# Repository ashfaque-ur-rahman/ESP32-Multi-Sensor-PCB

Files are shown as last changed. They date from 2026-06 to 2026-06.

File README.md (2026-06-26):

# ESP32-C3 Multi-Sensor PCB — 4-Layer Board
 
My most complex PCB design to date — an ESP32-C3 based multi-sensor IoT board featuring three sensors across a hierarchical, multi-sheet schematic. Designed over multiple days following the **Tech Explorations** tutorial series. This was my first experience with both 4-layer PCB stackup design and microphone amplifier circuit design.
 
---
 
## Preview
 
### Schematic — Root Page
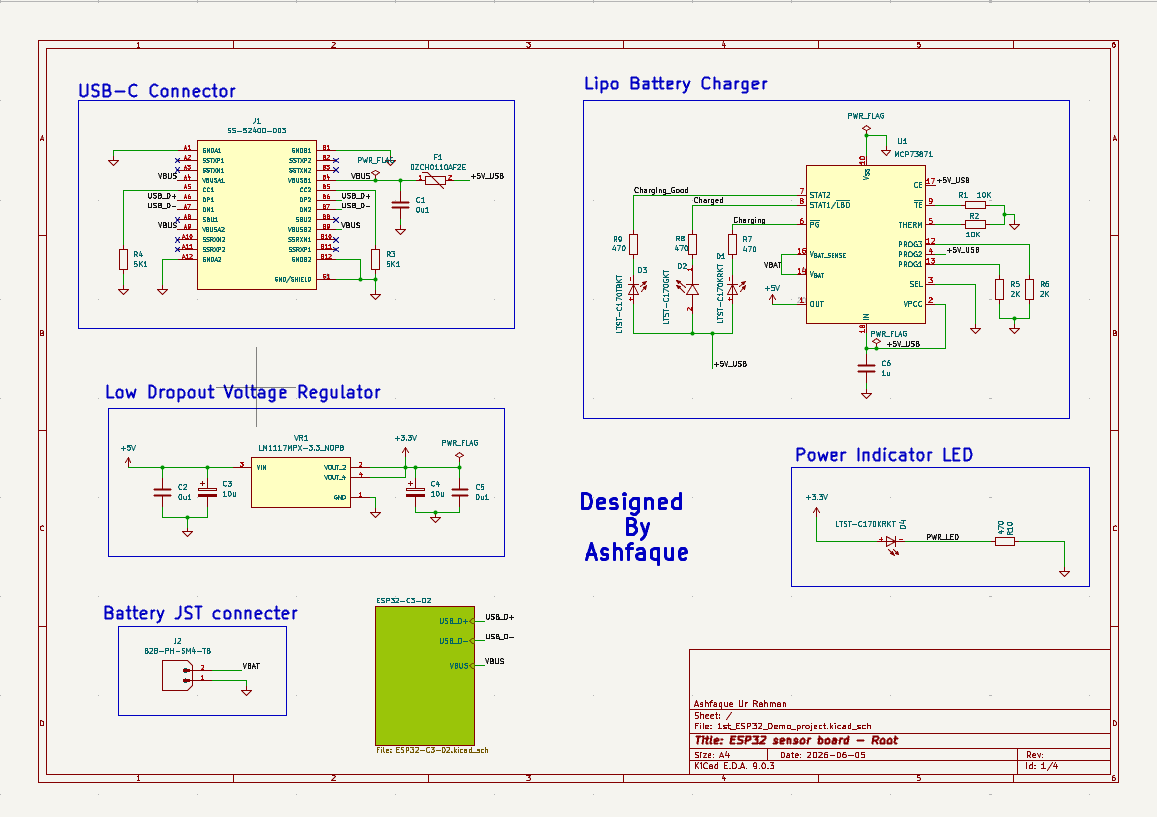
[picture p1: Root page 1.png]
Root Schematic

 
### Schematic — Sensors Sheet
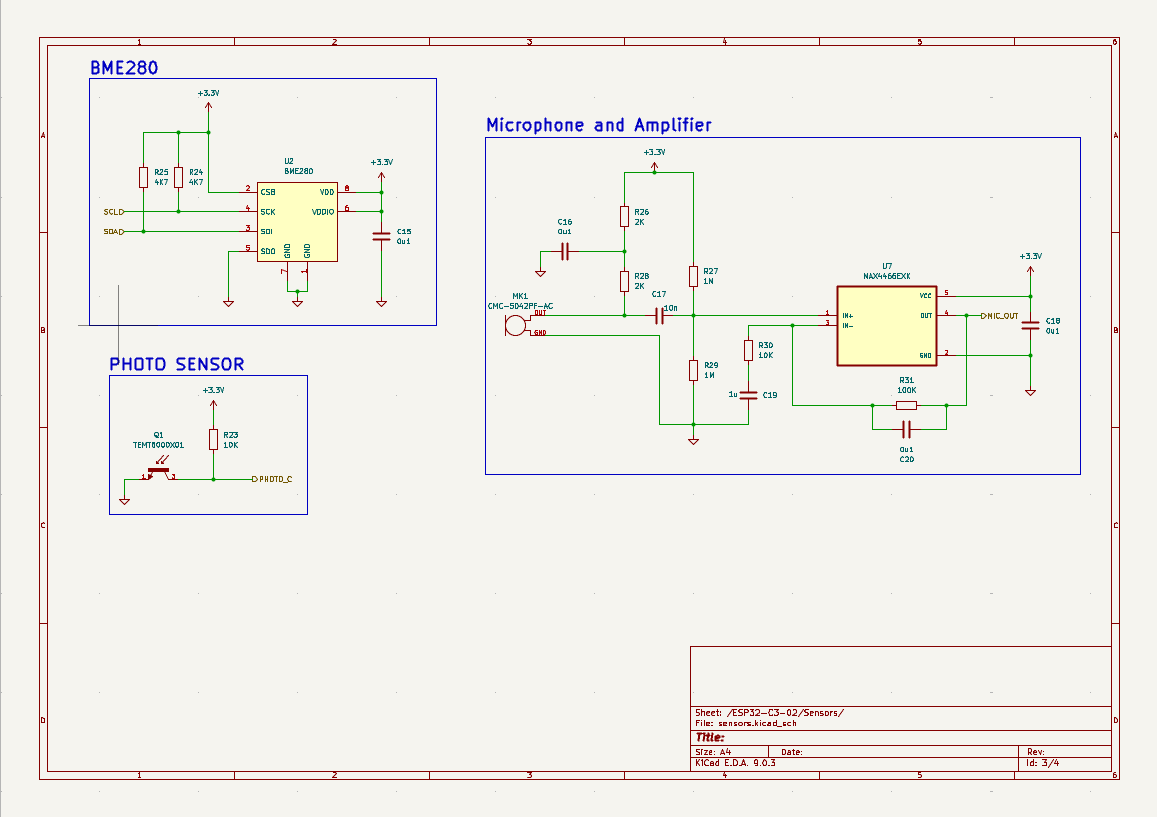
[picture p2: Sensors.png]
Sensors Schematic

 
### Schematic — Page 2
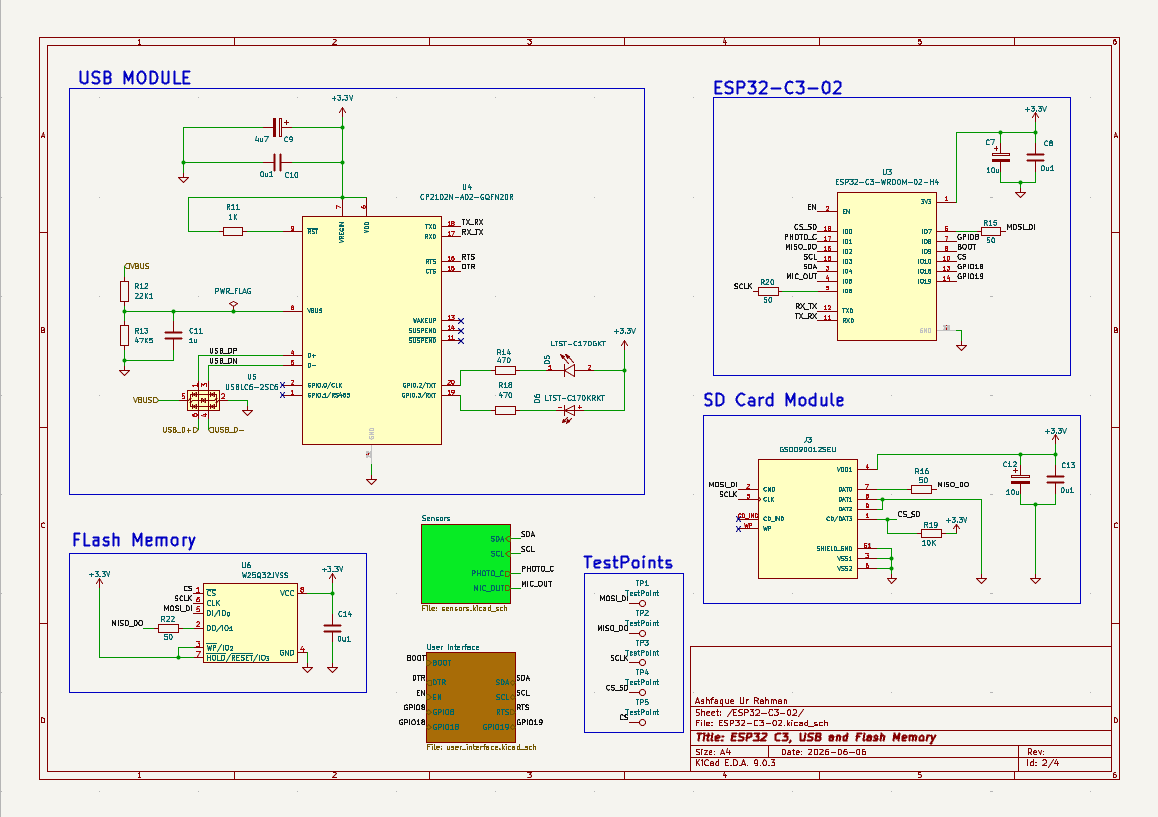
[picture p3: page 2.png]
Schematic Page 2

 
### Schematic — User Interface Sheet
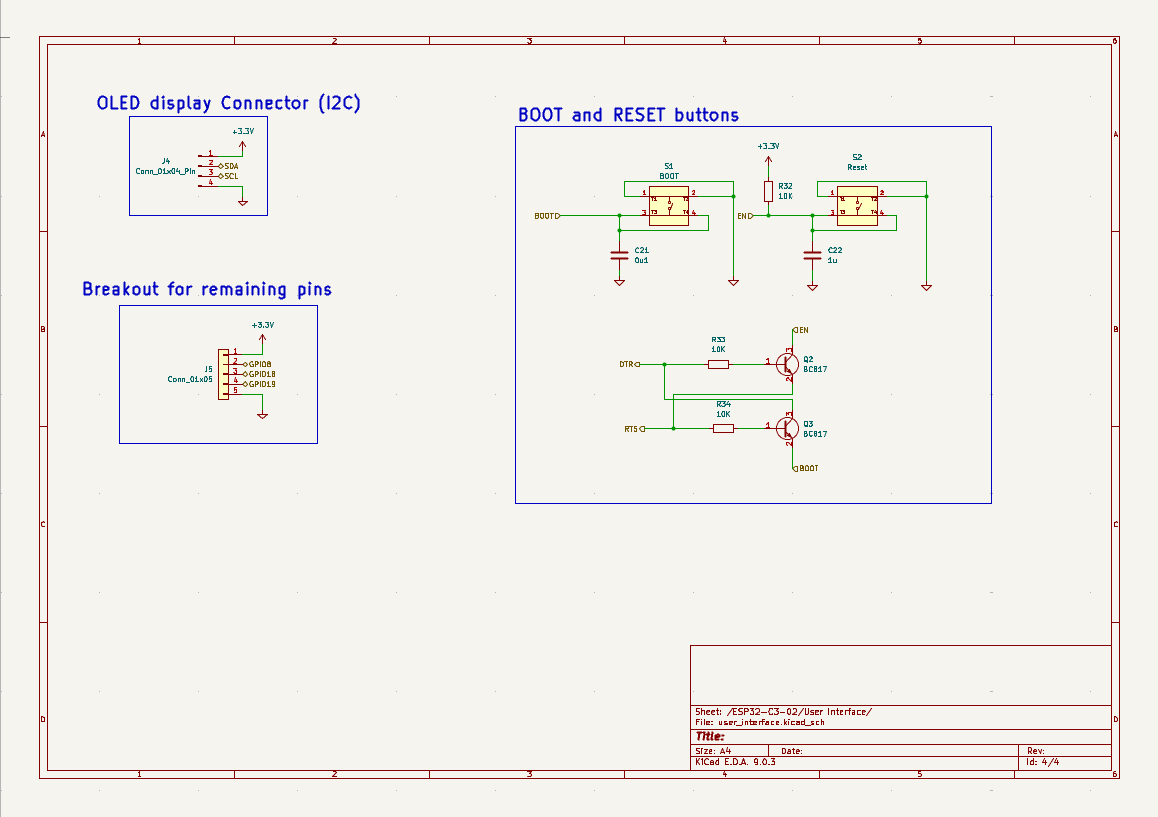
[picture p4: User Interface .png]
User Interface Schematic

 
### PCB Layout
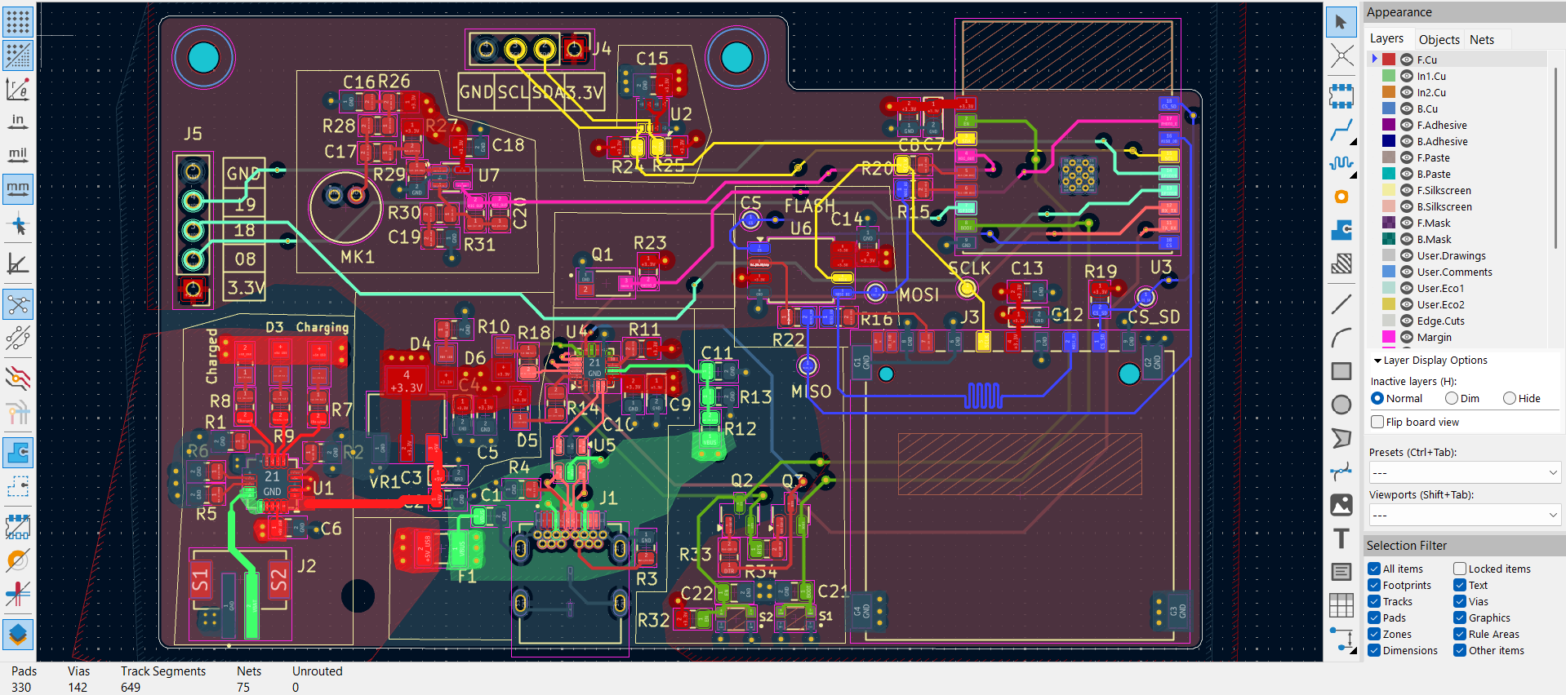
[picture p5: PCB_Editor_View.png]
PCB Layout

 
### 3D View
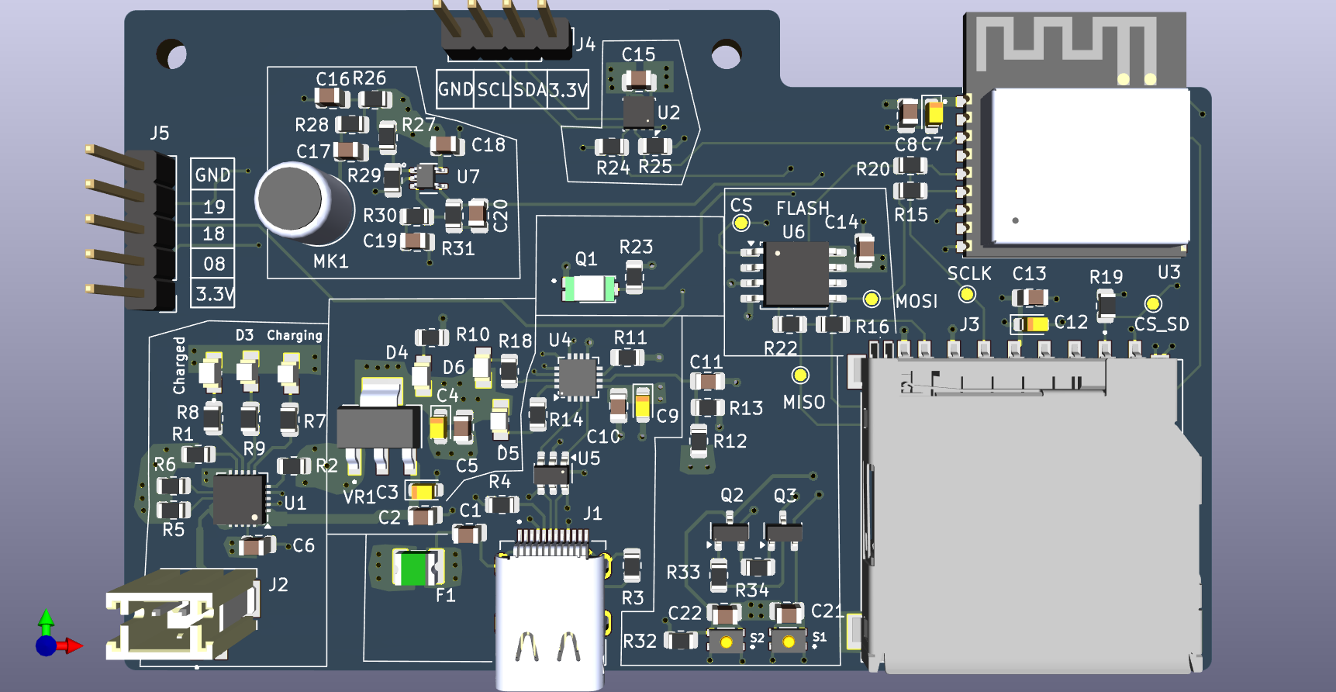
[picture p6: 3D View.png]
3D View

 
---
 
## Project overview
 
| Property | Details |
|---|---|
| **MCU** | ESP32-C3 |
| **Board layers** | 4-layer stackup |
| **Schematic structure** | Hierarchical — 3 separate sheets |
| **Sensors** | BME280, Electret Microphone + MAX4466EXK |
| **EDA Tool** | KiCad 9.0 |
| **Design reference** | Tech Explorations tutorial series |
| **Status** | Design complete |
 
---
 
## Board stackup
 
| Layer | Function |
|---|---|
| Layer 1 (Top) | Signal + components |
| Layer 2 | Ground plane (GND) |
| Layer 3 | Power plane (VCC) |
| Layer 4 (Bottom) | Signal |
 
A dedicated ground plane on Layer 2 ensures low-impedance returns for all sensors and clean power distribution — critical for analog microphone signal integrity.
 
---
 
## Sensors & key components
 
| Component | Part | Function | Interface |
|---|---|---|---|
| Environmental Sensor | BME280 (Bosch) | Temperature, humidity & pressure — 3-in-1 | I²C / SPI |
| Microphone | CMC-5042PF-AC (Same Sky) | 6mm omnidirectional electret condenser mic | Analog |
| Mic Amplifier | MAX4466EXK (Analog Devices) | Low-noise microphone amplifier, SC-70 package | Analog |
| MCU | ESP32-C3-02 | Wi-Fi + Bluetooth 5.0 LE microcontroller | — |
 
---
 
## Schematic structure
 
This design uses a **hierarchical multi-sheet schematic** — a professional approach for managing complex designs:
 
| Sheet | Contents |
|---|---|
| `Root page 1` | Top-level hierarchy, power distribution, ESP32-C3 core |
| `sensors.kicad_sch` | BME280 environmental sensor + microphone + MAX4466 amplifier circuit |
| `user_interface.kicad_sch` | User-facing connections, GPIO breakouts, connectors |
 
---
 
## Files included
 
### KiCad project files
| File | Description |
|---|---|
| `1st_ESP32_Demo_project.kicad_pro` | KiCad project file |
| `1st_ESP32_Demo_project.kicad_sch` | Root schematic |
| `ESP32-C3-02.kicad_sch` | ESP32-C3 sub-schematic sheet |
| `sensors.kicad_sch` | Sensors sub-schematic sheet |
| `user_interface.kicad_sch` | User interface sub-schematic sheet |
| `1st_ESP32_Demo_project.kicad_pcb` | PCB layout |
| `Footprints/` | Custom footprint library |
 
---
 
## What I learned
 
- 4-layer PCB stackup design with dedicated ground and power planes
- Hierarchical multi-sheet schematic design in KiCad 9.0
- BME280 I²C sensor integration with proper decoupling
- Electret condenser microphone biasing and signal conditioning
- MAX4466EXK low-noise amplifier circuit design
- Analog signal routing considerations on a mixed-signal PCB
- ESP32-C3 peripheral assignment and RF antenna clearance
---
 
## Tools used
 


 
---
 
## Reference
 
This design follows the **Tech Explorations ESP32 PCB Design tutorial series**.
 
> Tech Explorations: [https://www.youtube.com/@TechExplorations](https://www.youtube.com/@TechExplorations)
 
---
 
*Mymensingh Engineering College — EEE Department*

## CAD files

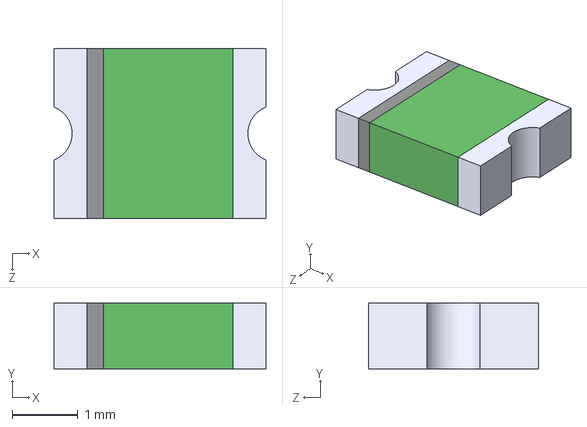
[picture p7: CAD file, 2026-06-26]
Footprints/0ZCH0110AF2E/0ZCH0110AF2E.step
3.21 x 1.00 x 2.58 mm

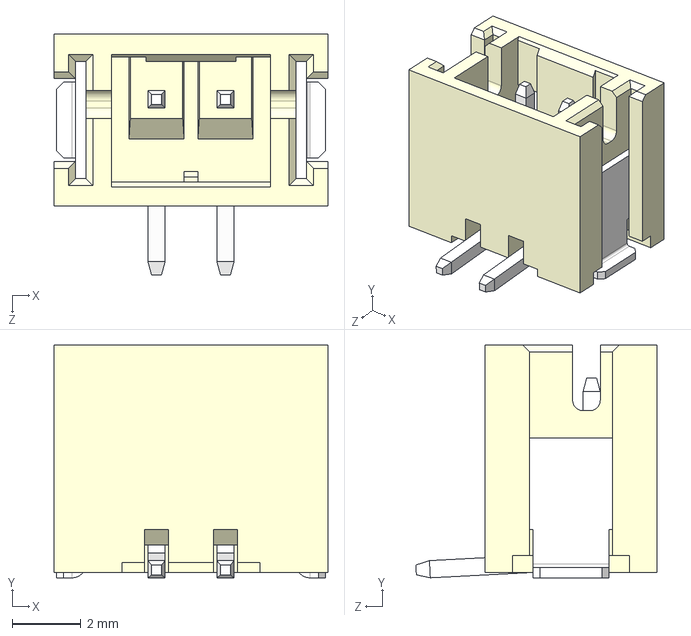
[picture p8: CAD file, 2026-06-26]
Footprints/B2B-PH-SM4-TB/B2B-PH-SM4-TB.step
7.95 x 6.75 x 7.00 mm

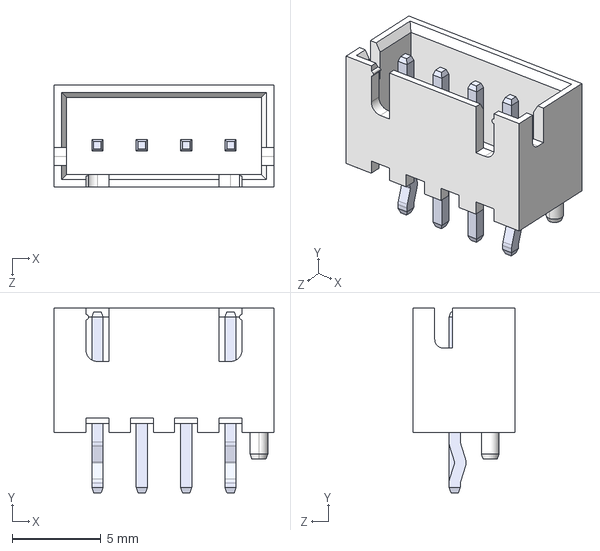
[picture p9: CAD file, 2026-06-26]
Footprints/B4B-XH-AM__LF__SN_/B4B-XH-AM__LF__SN_.step
12.4 x 10.4 x 5.75 mm

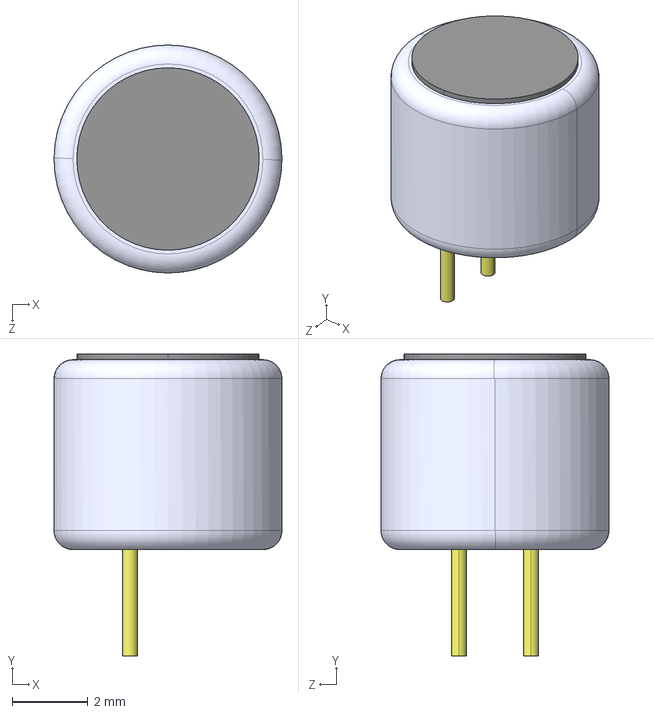
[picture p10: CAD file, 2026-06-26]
Footprints/CMC-5042PF-AC/CMC-5042PF-AC.step
6.00 x 7.95 x 6.00 mm

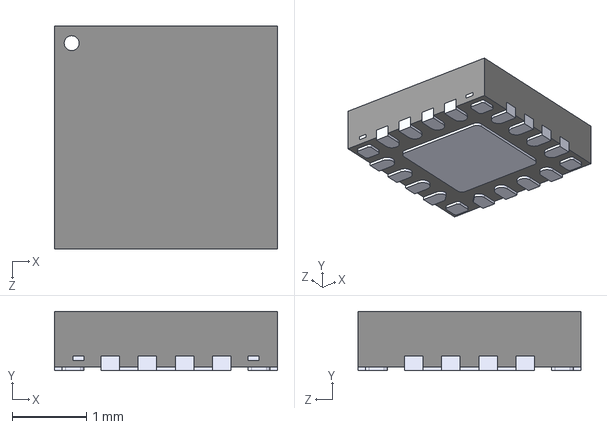
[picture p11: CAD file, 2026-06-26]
Footprints/CP2102N-A02-GQFN20R/CP2102N-A02-GQFN20R--3DModel-STEP-510211.STEP
3.00 x 0.8 x 3.00 mm

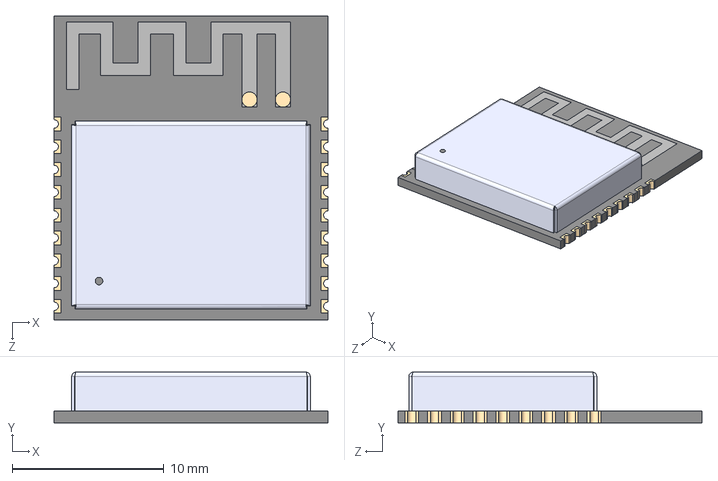
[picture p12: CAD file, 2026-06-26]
Footprints/ESP32-C3-WROOM-02-H4/ESP32-C3-WROOM-02-H4.step
18.0 x 3.35 x 20.0 mm

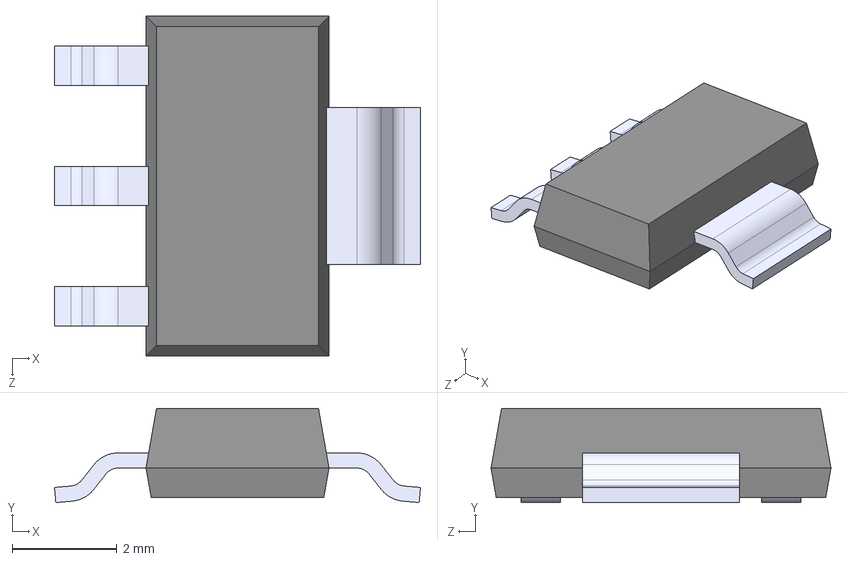
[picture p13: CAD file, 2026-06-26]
Footprints/LM1117MPX-3.3_NOPB/LM1117MPX-3.3_NOPB.step
7.00 x 1.80 x 6.50 mm

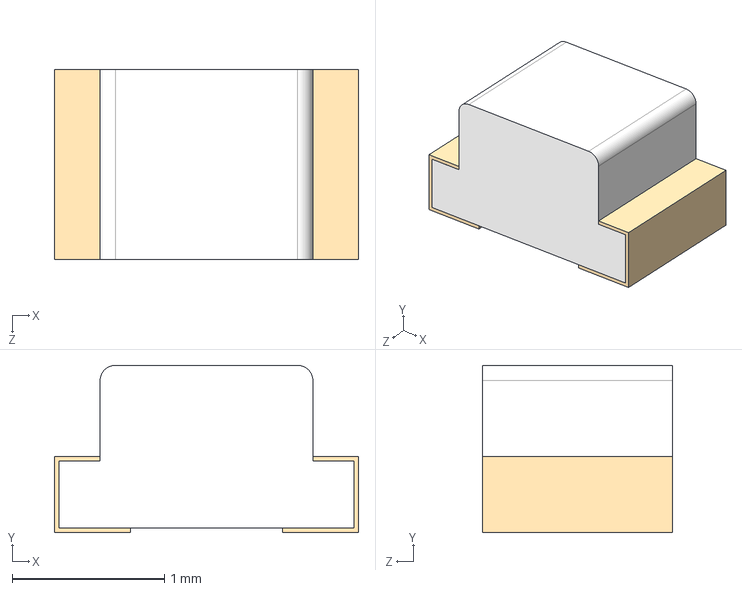
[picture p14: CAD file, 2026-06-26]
Footprints/LTST-C170GKT/LTST-C170GKT.step
2.00 x 1.10 x 1.25 mm

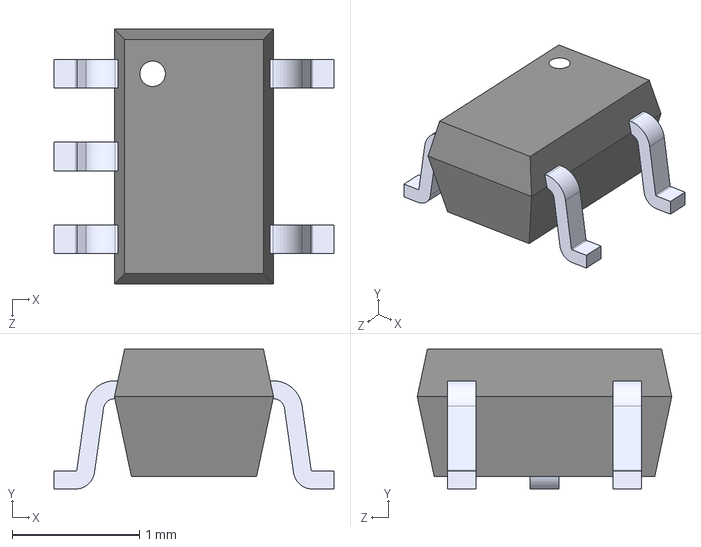
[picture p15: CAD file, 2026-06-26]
Footprints/MAX4466EXK/MAX4466EXK.step
2.20 x 1.10 x 2.00 mm

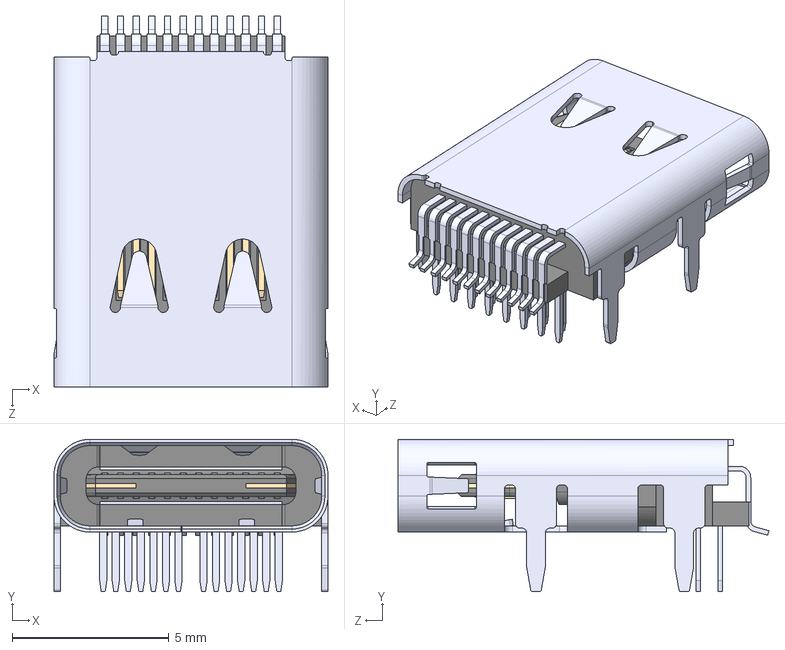
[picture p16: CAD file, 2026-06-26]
Footprints/SS-52400-003/SS-52400-003--3DModel-STEP-56544.STEP
8.74 x 4.86 x 11.8 mm

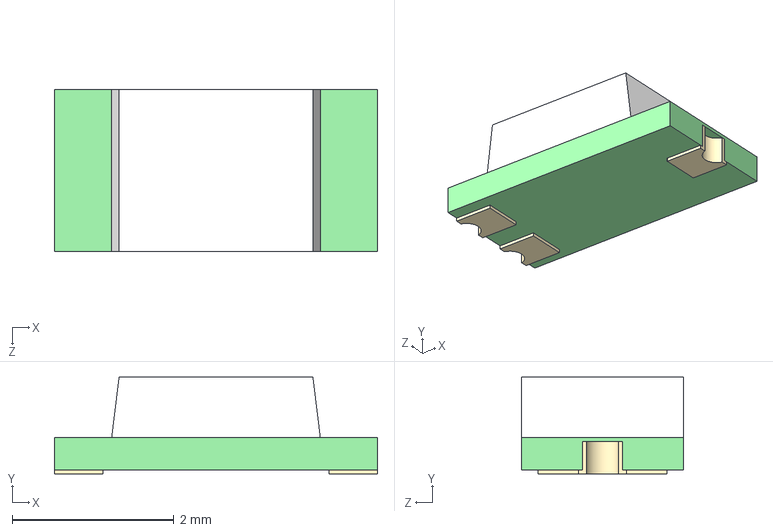
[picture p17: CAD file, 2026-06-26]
Footprints/TEMT6000X01/TEMT6000X01.step
4.00 x 1.20 x 2.00 mm

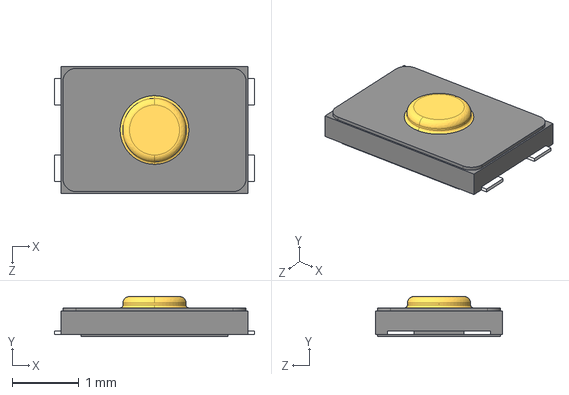
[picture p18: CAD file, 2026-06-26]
Footprints/USLPT2819DT2TR/USLPT2819DT2TR.step
3.00 x 0.6 x 1.90 mm

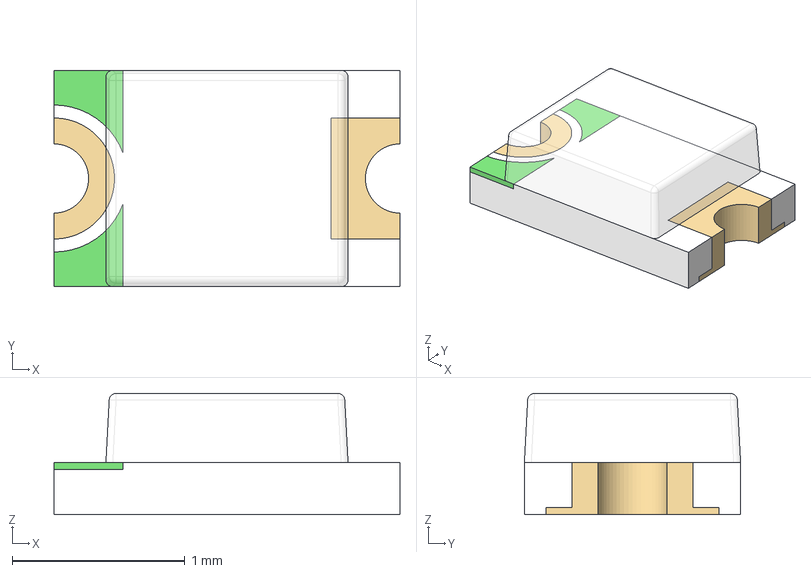
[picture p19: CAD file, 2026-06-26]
Footprints/WL-SMCW_0805/WL-SMCW_0805.step
2.00 x 1.25 x 0.7 mm
housing
marking x 2
cover
base_2
base

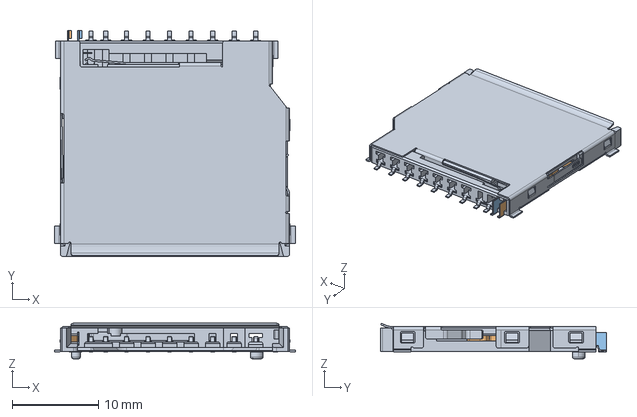
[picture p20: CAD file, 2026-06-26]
Footprints/GSD090012SEU/GSD090012SEU.step
28.0 x 26.2 x 4.13 mm

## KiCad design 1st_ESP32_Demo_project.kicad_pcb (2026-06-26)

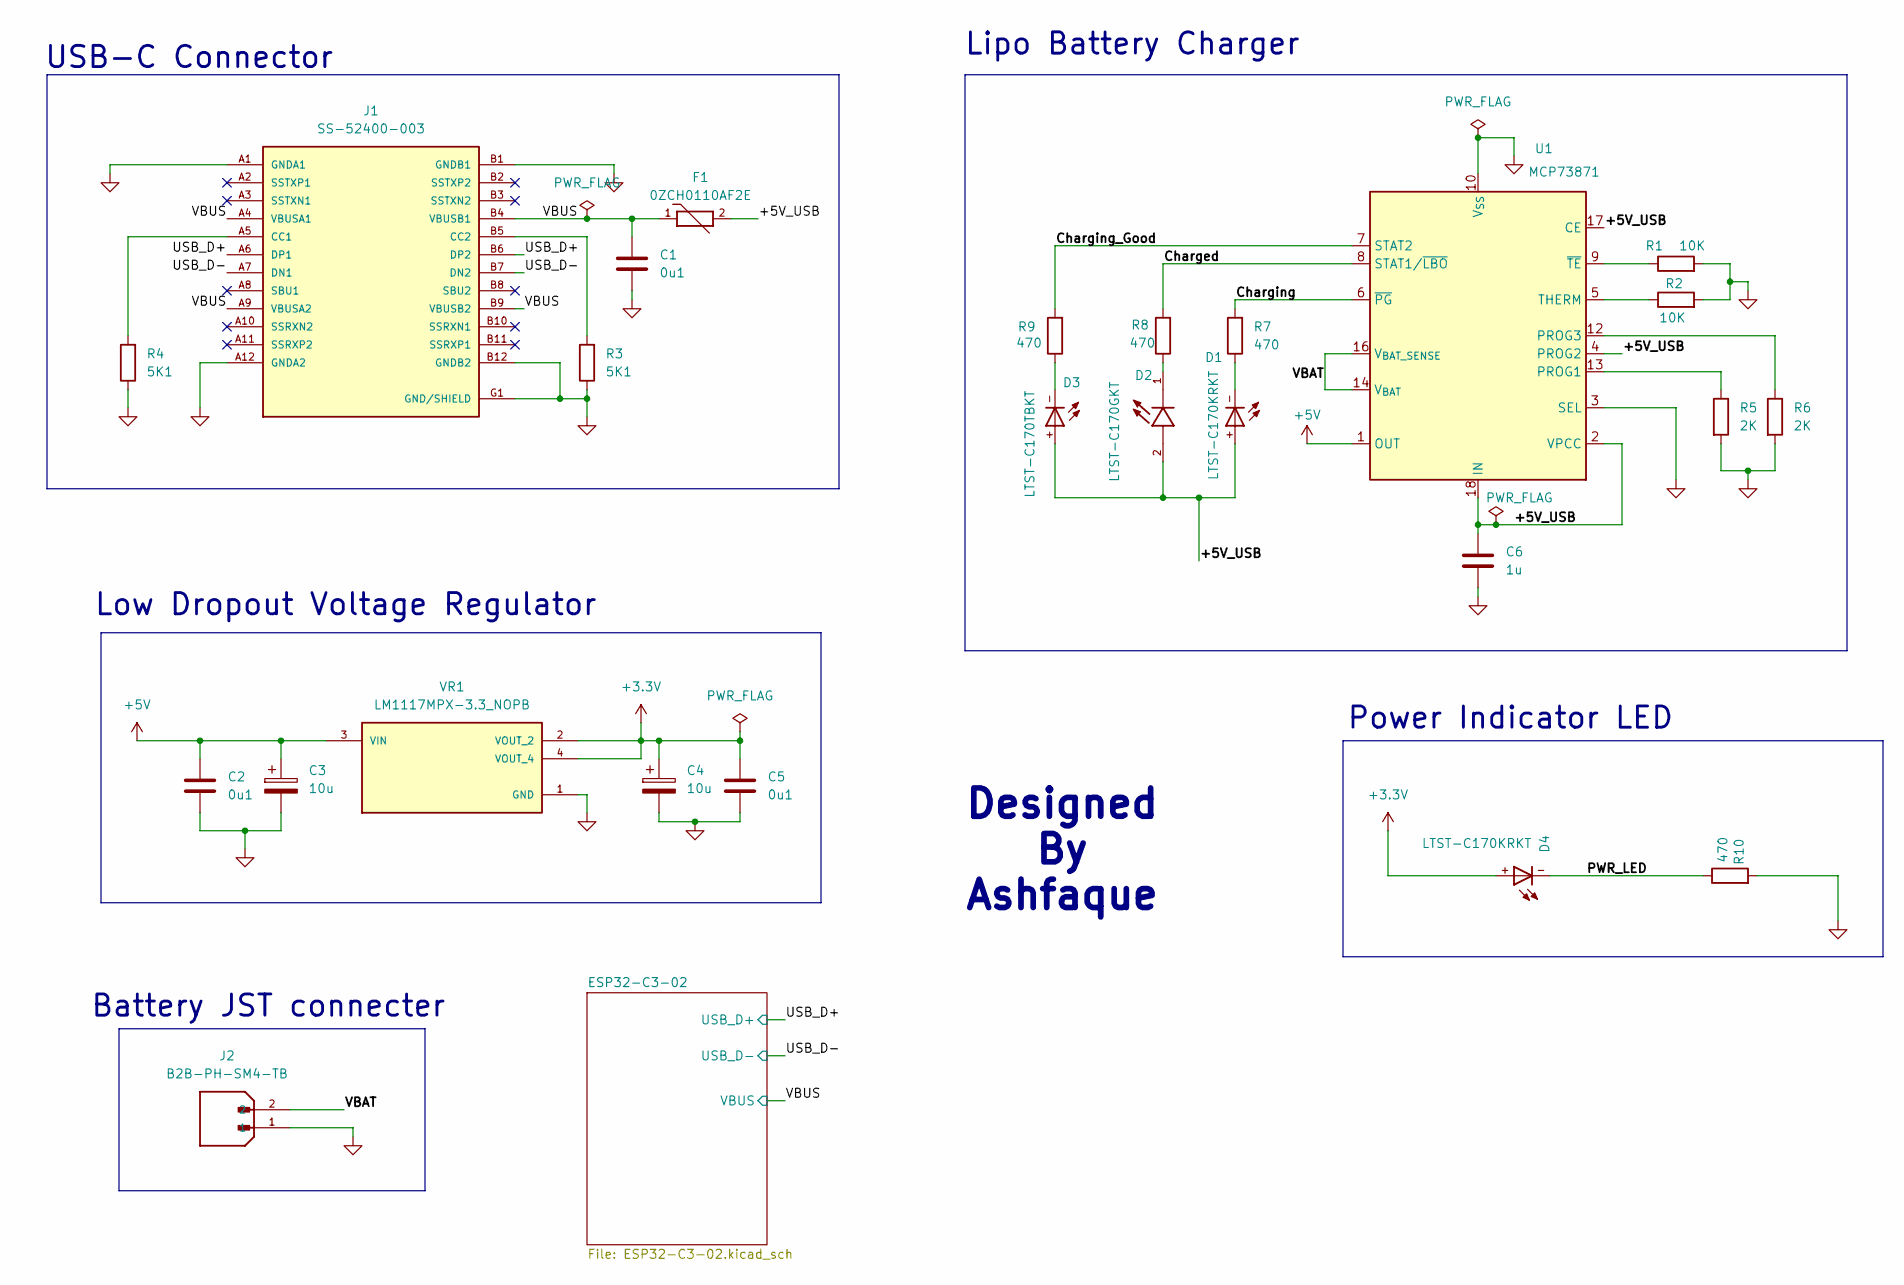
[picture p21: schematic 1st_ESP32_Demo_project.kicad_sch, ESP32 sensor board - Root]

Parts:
C1, C2, C5: 0u1; C_0805_2012Metric
C3, C4: 10u; CP_EIA-2012-12_Kemet-R
C6: 1u; C_0805_2012Metric
D1, D4: LTST-C170KRKT; DIOC200X125X110
D2: LTST-C170GKT; LED_LTST-C170GKT; PARTREV I
D3: LTST-C170TBKT; DIOC200X125X110
F1: 0ZCH0110AF2E; FUSC3225X100N; PARTREV Apr2023
J1: SS-52400-003; BELFUSE_SS-52400-003; PARTREV A0
J2: B2B-PH-SM4-TB; JST_B2B-PH-SM4-TB; PARTREV N/A
R1, R2: 10K; R_0805_2012Metric
R3, R4: 5K1; R_0805_2012Metric
R5, R6: 2K; R_0805_2012Metric
R7, R8, R9, R10: 470; R_0805_2012Metric
U1: MCP73871; QFN-20-1EP_4x4mm_P0.5mm_EP2.5x2.5mm
VR1: LM1117MPX-3.3_NOPB; VREG_LM1117MPX-3.3_NOPB; PARTREV O

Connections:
+3.3V: C4.1, C5.1, D4.+, VR1.2 (VOUT_2), VR1.4 (VOUT_4); also elsewhere on the board
+5V: C2.1, C3.1, U1.1 (OUT), U1.20 (OUT), VR1.3 (VIN)
/+5V_USB: C6.1, D1.+, D2.2, D3.+, F1.2, U1.2 (VPCC), U1.4 (PROG2), U1.17 (CE), U1.18 (IN), U1.19 (IN); also elsewhere on the board
/Charged: R8.2, U1.8 (STAT1/~LBO)
/Charging: R7.2, U1.6 (~PG)
/Charging_Good: R9.2, U1.7 (STAT2)
/PWR_LED: D4.-, R10.1
/USB_D+: J1.A6 (DP1), J1.B6 (DP2); also elsewhere on the board
/USB_D-: J1.A7 (DN1), J1.B7 (DN2); also elsewhere on the board
/VBAT: J2.2, U1.14 (V_{BAT}), U1.15 (V_{BAT}), U1.16 (V_{BAT_SENSE})
/VBUS: C1.1, F1.1, J1.A4 (VBUSA1), J1.A9 (VBUSA2), J1.B4 (VBUSB1), J1.B9 (VBUSB2); also elsewhere on the board
GND: C1.2, C2.2, C3.2, C4.2, C5.2, C6.2, J1.A1 (GNDA1), J1.A12 (GNDA2), J1.B1 (GNDB1), J1.B12 (GNDB2), J1.G1 (GND/SHIELD), J1.G2 (GND/SHIELD), J1.G3 (GND/SHIELD), J1.G4 (GND/SHIELD), J1.S1 (GND/SHIELD), J1.S2 (GND/SHIELD), J1.S3 (GND/SHIELD), J1.S4 (GND/SHIELD), J2.1, R1.2, R2.2, R3.1, R4.1, R5.2, R6.2, R10.2, U1.3 (SEL), U1.10 (V_{SS}), U1.11 (V_{SS}), U1.21 (V_{SS}), VR1.1 (GND); also elsewhere on the board
unnamed 35: D1.-, R7.1; also elsewhere on the board
unnamed 36: D2.1, R8.1; also elsewhere on the board
unnamed: D3.-, R9.1
unnamed: J1.A5 (CC1), R4.2
unnamed: J1.B5 (CC2), R3.2
unnamed: R5.1, U1.13 (PROG1)
unnamed: R6.1, U1.12 (PROG3)
unnamed: R2.1, U1.5 (THERM)
unnamed: R1.1, U1.9 (~TE)

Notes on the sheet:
Lipo Battery Charger
USB-C Connector
Battery JST connecter
Designed By Ashfaque
Power Indicator LED
Low Dropout Voltage Regulator

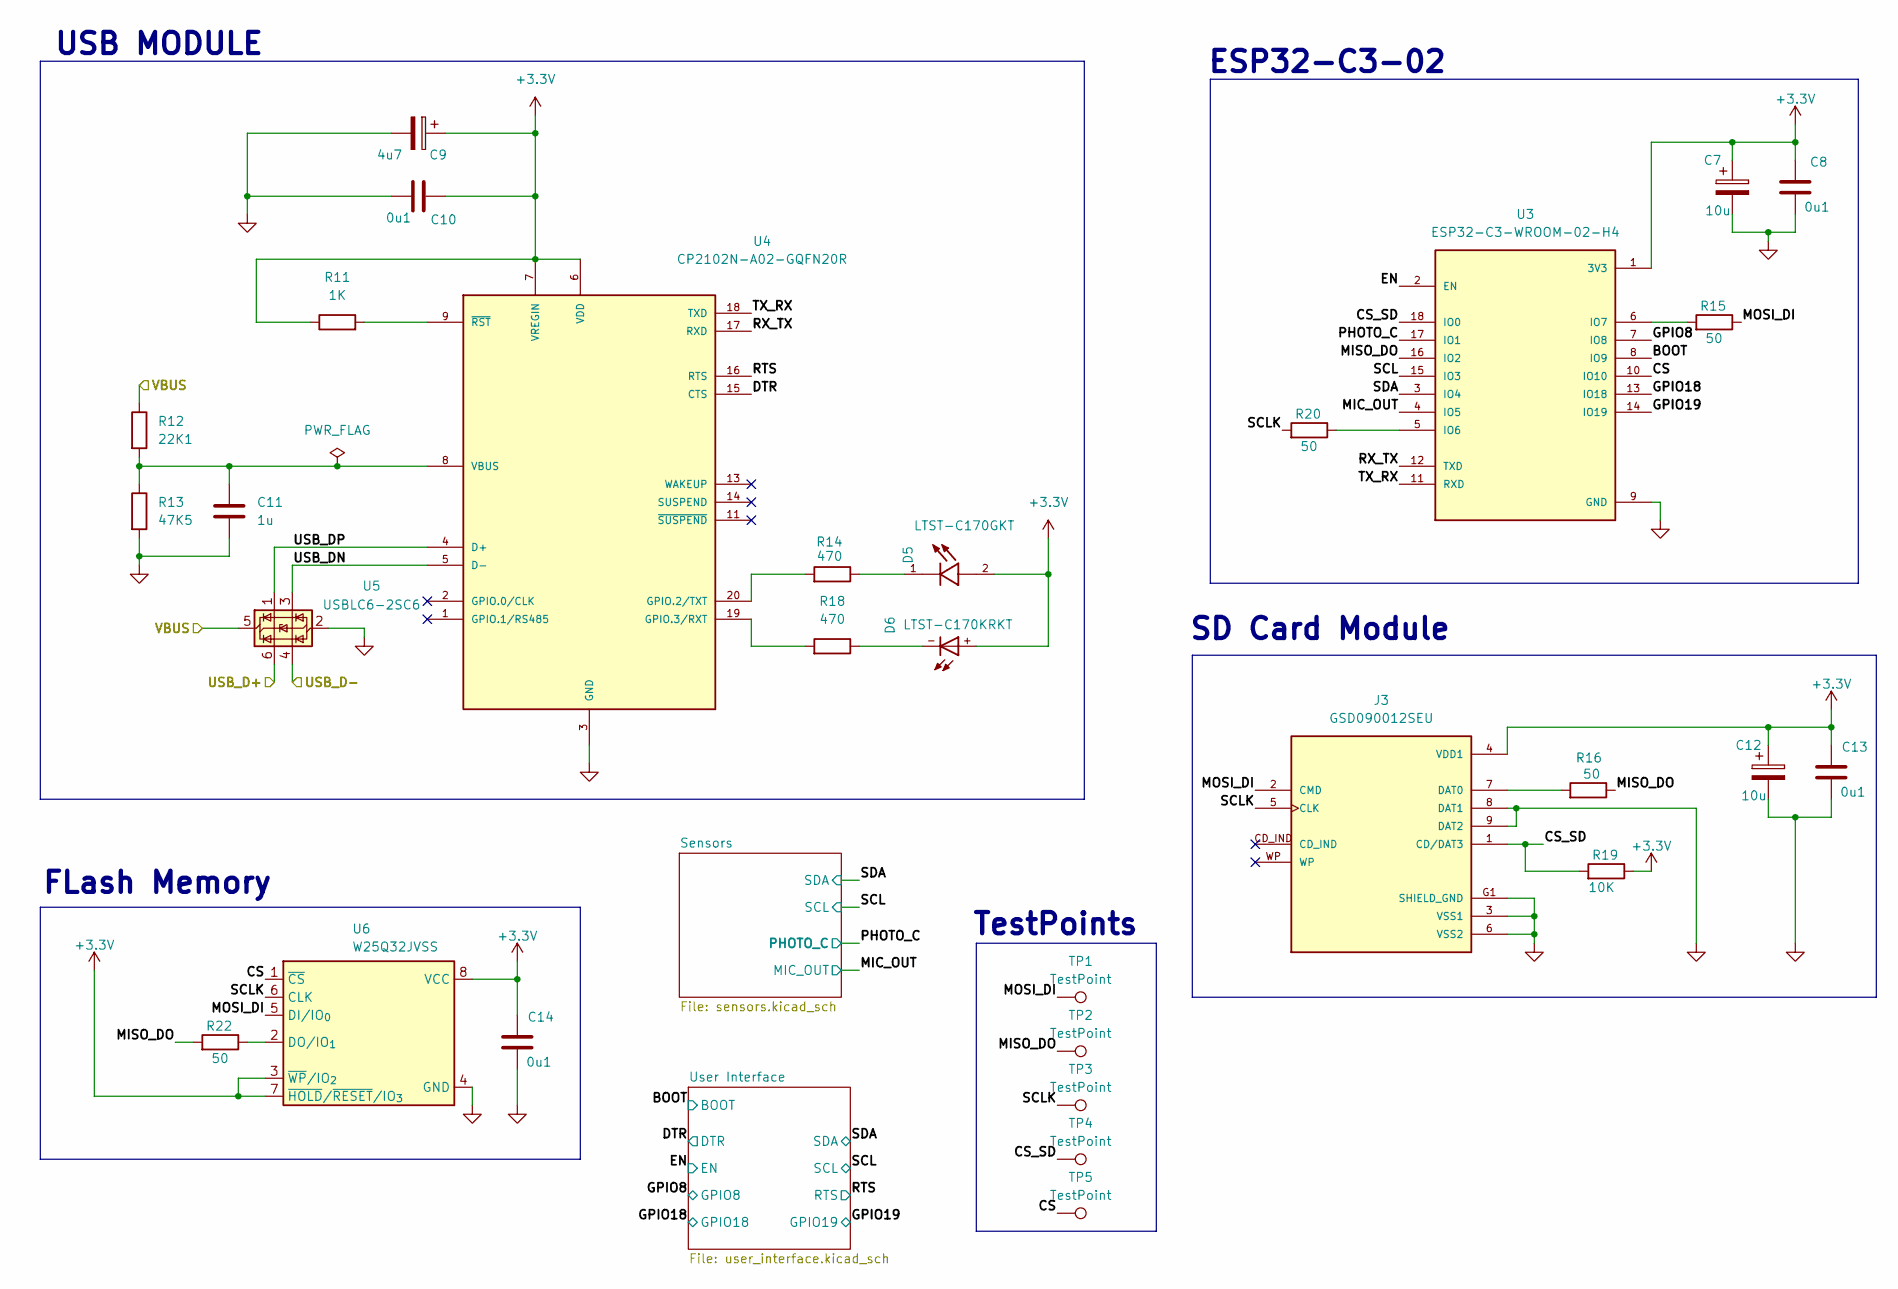
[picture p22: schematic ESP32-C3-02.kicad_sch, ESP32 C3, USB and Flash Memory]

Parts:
C7, C12: 10u; CP_EIA-2012-12_Kemet-R
C8, C10, C13, C14: 0u1; C_0805_2012Metric
C9: 4u7; CP_EIA-2012-12_Kemet-R
C11: 1u; C_0805_2012Metric
D5: LTST-C170GKT; LED_LTST-C170GKT; PARTREV I
D6: LTST-C170KRKT; DIOC200X125X110
J3: GSD090012SEU; AMPHENOL_GSD090012SEU; PARTREV E
R11: 1K; R_0805_2012Metric
R12: 22K1; R_0805_2012Metric
R13: 47K5; R_0805_2012Metric
R14, R18: 470; R_0805_2012Metric
R15, R16, R20, R22: 50; R_0805_2012Metric
R19: 10K; R_0805_2012Metric
TP1, TP2, TP3, TP4, TP5: TestPoint; TestPoint_Pad_D1.0mm
U3: ESP32-C3-WROOM-02-H4; MODULE_ESP32-C3-WROOM-02-H4
U4: CP2102N-A02-GQFN20R; SiliconLabs_QFN-20-1EP_3x3mm_P0.5mm_EP1.8x1.8mm; PARTREV 1.3
U5: USBLC6-2SC6; SOT-23-6
U6: W25Q32JVSS; SOIC-8_5.3x5.3mm_P1.27mm

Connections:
+3.3V: C7.1, C8.2, C9.1, C10.2, C12.1, C13.2, C14.2, D5.2, D6.+, J3.4 (VDD1), R11.1, R19.1, U3.1 (3V3), U4.6 (VDD), U4.7 (VREGIN), U6.3 (~WP/IO_{2}), U6.7 (~HOLD/~RESET/IO_{3}), U6.8 (VCC); also elsewhere on the board
/ESP32-C3-02/BOOT: U3.8 (IO9); also elsewhere on the board
/ESP32-C3-02/CS: TP5.1, U3.10 (IO10), U6.1 (~CS); also elsewhere on the board
/ESP32-C3-02/CS_SD: J3.1 (CD/DAT3), R19.2, TP4.1, U3.18 (IO0); also elsewhere on the board
/ESP32-C3-02/DTR: U4.15 (CTS); also elsewhere on the board
/ESP32-C3-02/EN: U3.2 (EN); also elsewhere on the board
/ESP32-C3-02/GPIO8: U3.7 (IO8); also elsewhere on the board
/ESP32-C3-02/GPIO18: U3.13 (IO18); also elsewhere on the board
/ESP32-C3-02/GPIO19: U3.14 (IO19); also elsewhere on the board
/ESP32-C3-02/MIC_OUT: U3.4 (IO5); also elsewhere on the board
/ESP32-C3-02/MISO_DO: R16.1, R22.2, TP2.1, U3.16 (IO2); also elsewhere on the board
/ESP32-C3-02/MOSI_DI: J3.2 (CMD), R15.1, TP1.1, U6.5 (DI/IO_{0}); also elsewhere on the board
/ESP32-C3-02/PHOTO_C: U3.17 (IO1); also elsewhere on the board
/ESP32-C3-02/RTS: U4.16 (RTS); also elsewhere on the board
/ESP32-C3-02/RX_TX: U3.12 (TXD), U4.17 (RXD)
/ESP32-C3-02/SCL: U3.15 (IO3); also elsewhere on the board
/ESP32-C3-02/SCLK: J3.5 (CLK), R20.2, TP3.1, U6.6 (CLK); also elsewhere on the board
/ESP32-C3-02/SDA: U3.3 (IO4); also elsewhere on the board
/ESP32-C3-02/TX_RX: U3.11 (RXD), U4.18 (TXD)
/ESP32-C3-02/USB_DN: U4.5 (D-), U5.3 (I/O2)
/ESP32-C3-02/USB_DP: U4.4 (D+), U5.1 (I/O1)
/USB_D+: U5.6 (I/O1); also elsewhere on the board
/USB_D-: U5.4 (I/O2); also elsewhere on the board
/VBUS: R12.1, U5.5 (VBUS); also elsewhere on the board
GND: C7.2, C8.1, C9.2, C10.1, C11.2, C12.2, C13.1, C14.1, J3.3 (VSS1), J3.6 (VSS2), J3.8 (DAT1), J3.9 (DAT2), J3.G1 (SHIELD_GND), J3.G2 (SHIELD_GND), J3.G3 (SHIELD_GND), J3.G4 (SHIELD_GND), R13.2, U3.9 (GND), U3.19 (GND), U3.20 (GND), U3.21 (GND), U3.22 (GND), U3.23 (GND), U3.24 (GND), U3.25 (GND), U3.26 (GND), U3.27 (GND), U3.28 (GND), U3.29 (GND), U3.30 (GND), U3.31 (GND), U3.32 (GND), U3.33 (GND), U3.34 (GND), U3.35 (GND), U3.36 (GND), U3.37 (GND), U3.38 (GND), U3.39 (GND), U4.3 (GND), U4.12 (GND), U4.21 (GND), U5.2 (GND), U6.4 (GND); also elsewhere on the board
unnamed: D5.1, R14.1
unnamed: D6.-, R18.1
unnamed: J3.7 (DAT0), R16.2
unnamed: R20.1, U3.5 (IO6)
unnamed: R15.2, U3.6 (IO7)
unnamed: R14.2, U4.20 (GPIO.2/TXT)
unnamed: R18.2, U4.19 (GPIO.3/RXT)
unnamed: C11.1, R12.2, R13.1, U4.8 (VBUS)
unnamed: R11.2, U4.9 (~RST)
unnamed: R22.1, U6.2 (DO/IO_{1})

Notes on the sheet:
USB MODULE
FLash Memory
ESP32-C3-02
TestPoints
SD Card Module

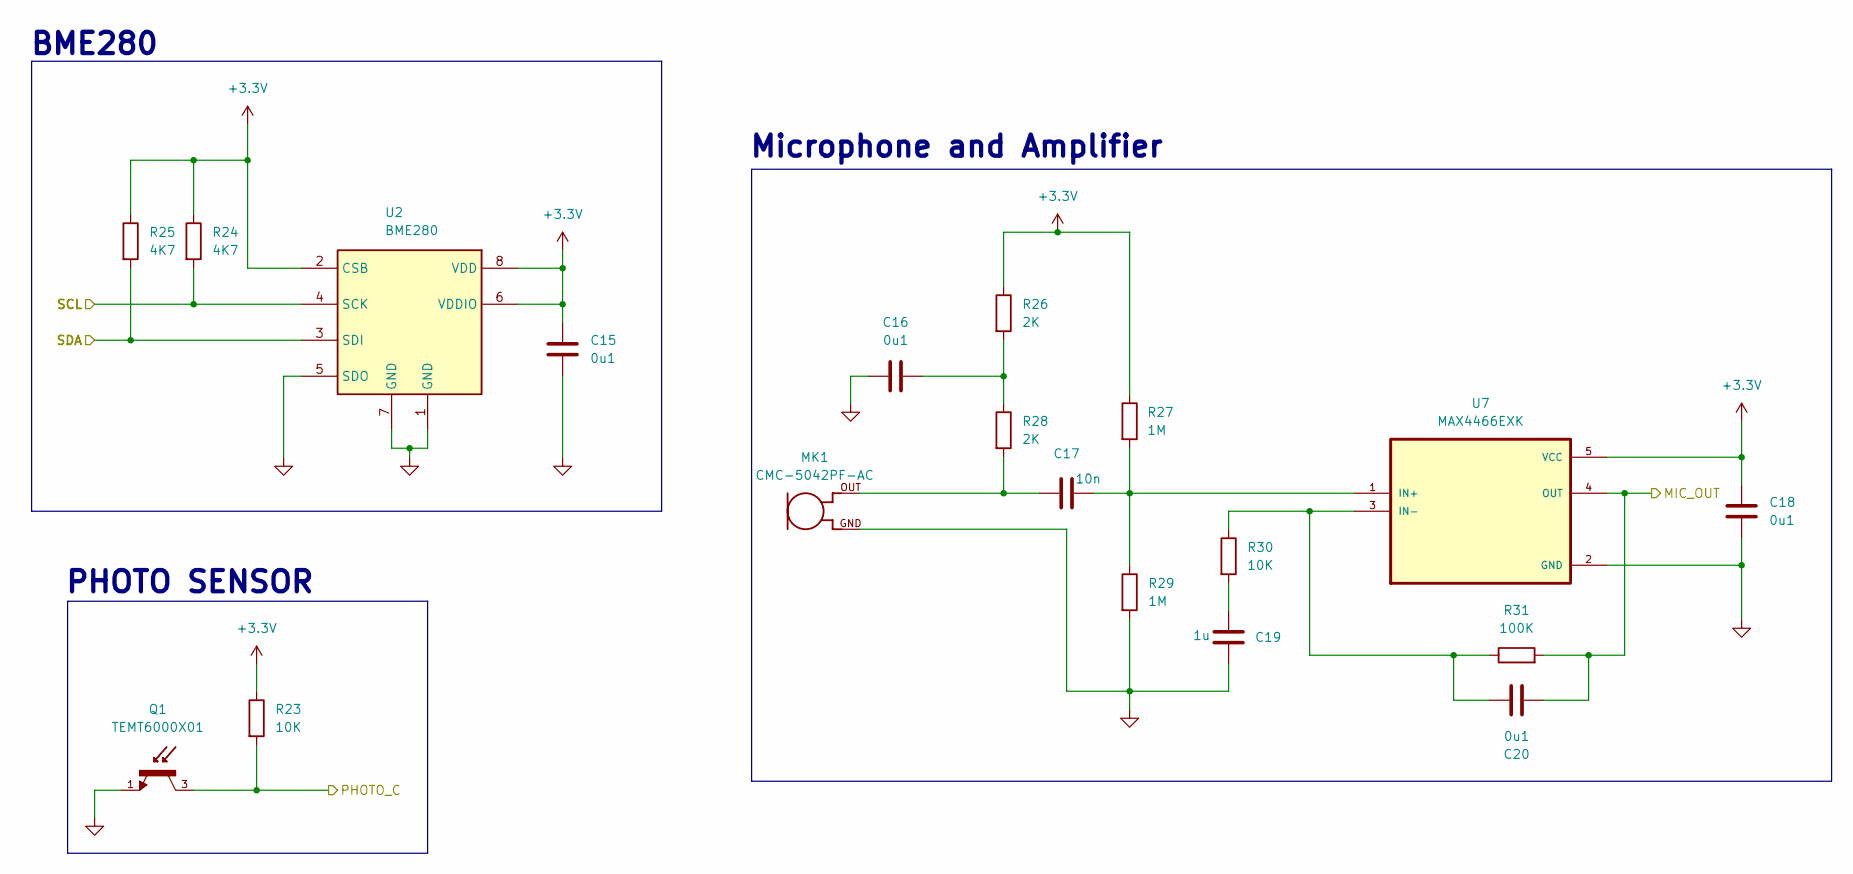
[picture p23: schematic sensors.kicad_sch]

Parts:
C15, C16, C18, C20: 0u1; C_0805_2012Metric
C17: 10n; C_0805_2012Metric
C19: 1u; C_0805_2012Metric
MK1: CMC-5042PF-AC; CUI_CMC-5042PF-AC
Q1: TEMT6000X01; TRANS_TEMT6000X01; PARTREV 1.9
R23, R30: 10K; R_0805_2012Metric
R24, R25: 4K7; R_0805_2012Metric
R26, R28: 2K; R_0805_2012Metric
R27, R29: 1M; R_0805_2012Metric
R31: 100K; R_0805_2012Metric
U2: BME280; Bosch_LGA-8_2.5x2.5mm_P0.65mm_ClockwisePinNumbering
U7: MAX4466EXK; SOT65P210X110-5N

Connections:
+3.3V: C15.1, C18.1, R23.1, R24.1, R25.1, R26.1, R27.1, U2.2 (CSB), U2.6 (VDDIO), U2.8 (VDD), U7.5 (VCC); also elsewhere on the board
/ESP32-C3-02/MIC_OUT: C20.2, R31.2, U7.4 (OUT); also elsewhere on the board
/ESP32-C3-02/PHOTO_C: Q1.3, R23.2; also elsewhere on the board
/ESP32-C3-02/SCL: R24.2, U2.4 (SCK); also elsewhere on the board
/ESP32-C3-02/SDA: R25.2, U2.3 (SDI); also elsewhere on the board
GND: C15.2, C16.1, C18.2, C19.1, MK1.GND, Q1.1, R29.2, U2.1 (GND), U2.5 (SDO), U2.7 (GND), U7.2 (GND); also elsewhere on the board
unnamed: C16.2, R26.2, R28.1
unnamed: C17.2, MK1.OUT, R28.2
unnamed: C19.2, R30.2
unnamed: C17.1, R27.2, R29.1, U7.1 (IN+)
unnamed: C20.1, R30.1, R31.1, U7.3 (IN-)

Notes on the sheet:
BME280
Microphone and Amplifier
PHOTO SENSOR

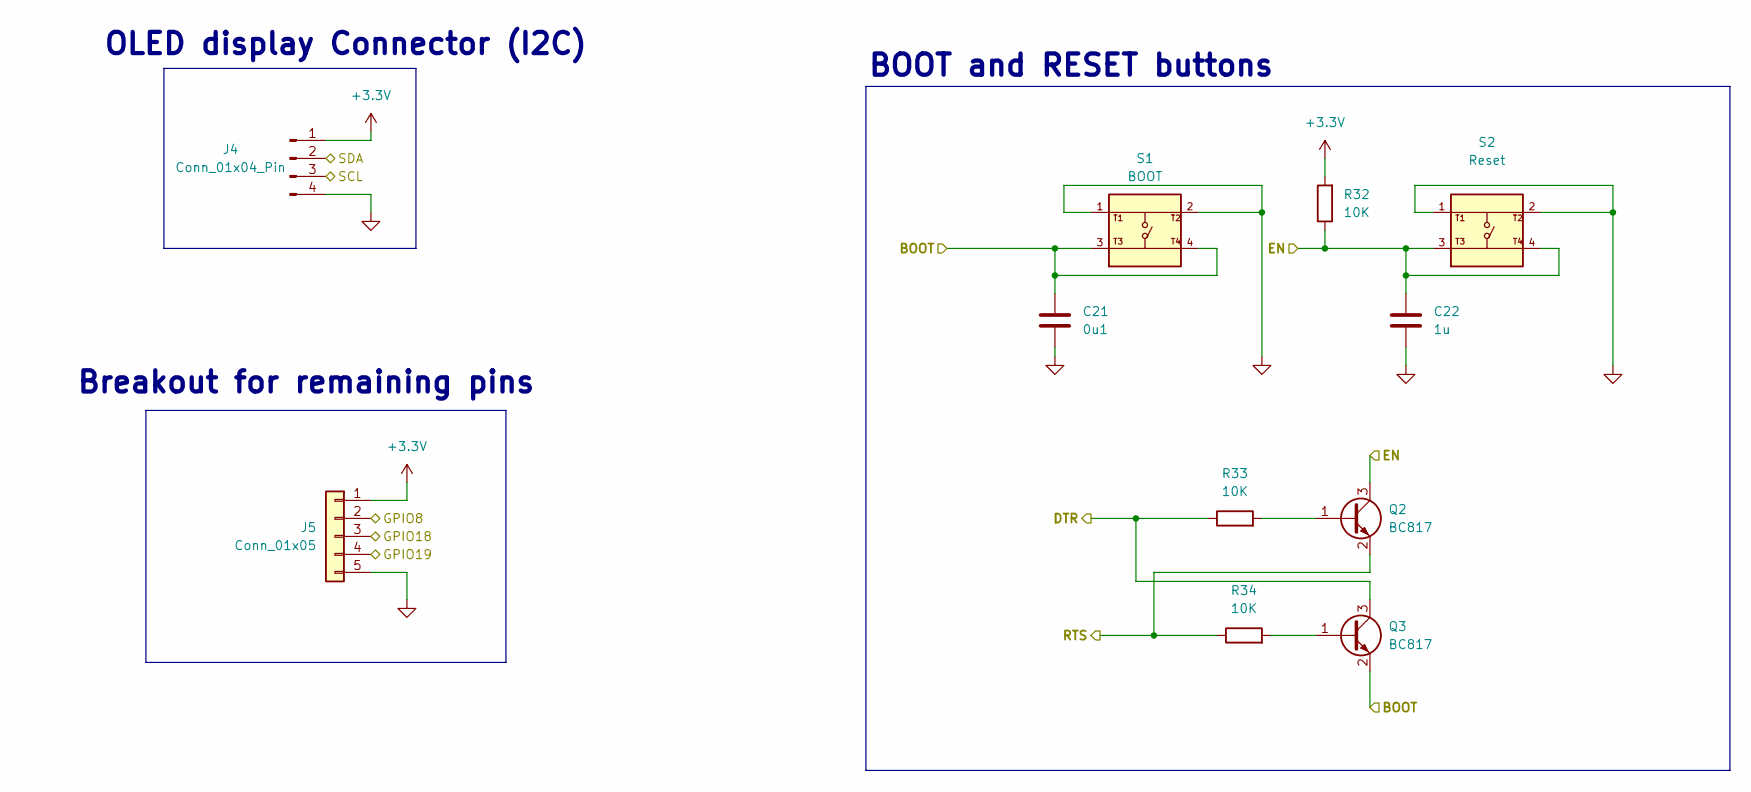
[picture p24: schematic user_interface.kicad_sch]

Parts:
C21: 0u1; C_0805_2012Metric
C22: 1u; C_0805_2012Metric
J4: Conn_01x04_Pin; PinHeader_1x04_P2.54mm_Vertical
J5: Conn_01x05; PinHeader_1x05_P2.54mm_Vertical
Q2, Q3: BC817; SOT-23
R32, R33, R34: 10K; R_0805_2012Metric
S1: BOOT; SW_USLPT2819DT2TR; PARTREV P
S2: Reset; SW_USLPT2819DT2TR; PARTREV P

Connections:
+3.3V: J4.1, J5.1, R32.2; also elsewhere on the board
/ESP32-C3-02/BOOT: C21.1, Q3.2 (E), S1.3, S1.4; also elsewhere on the board
/ESP32-C3-02/DTR: Q3.3 (C), R33.1; also elsewhere on the board
/ESP32-C3-02/EN: C22.1, Q2.3 (C), R32.1, S2.3, S2.4; also elsewhere on the board
/ESP32-C3-02/GPIO8: J5.2; also elsewhere on the board
/ESP32-C3-02/GPIO18: J5.3; also elsewhere on the board
/ESP32-C3-02/GPIO19: J5.4; also elsewhere on the board
/ESP32-C3-02/RTS: Q2.2 (E), R34.1; also elsewhere on the board
/ESP32-C3-02/SCL: J4.3; also elsewhere on the board
/ESP32-C3-02/SDA: J4.2; also elsewhere on the board
GND: C21.2, C22.2, J4.4, J5.5, S1.1, S1.2, S2.1, S2.2; also elsewhere on the board
unnamed: Q2.1 (B), R33.2
unnamed: Q3.1 (B), R34.2

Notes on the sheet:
OLED display Connector (I2C)
Breakout for remaining pins
BOOT and RESET buttons

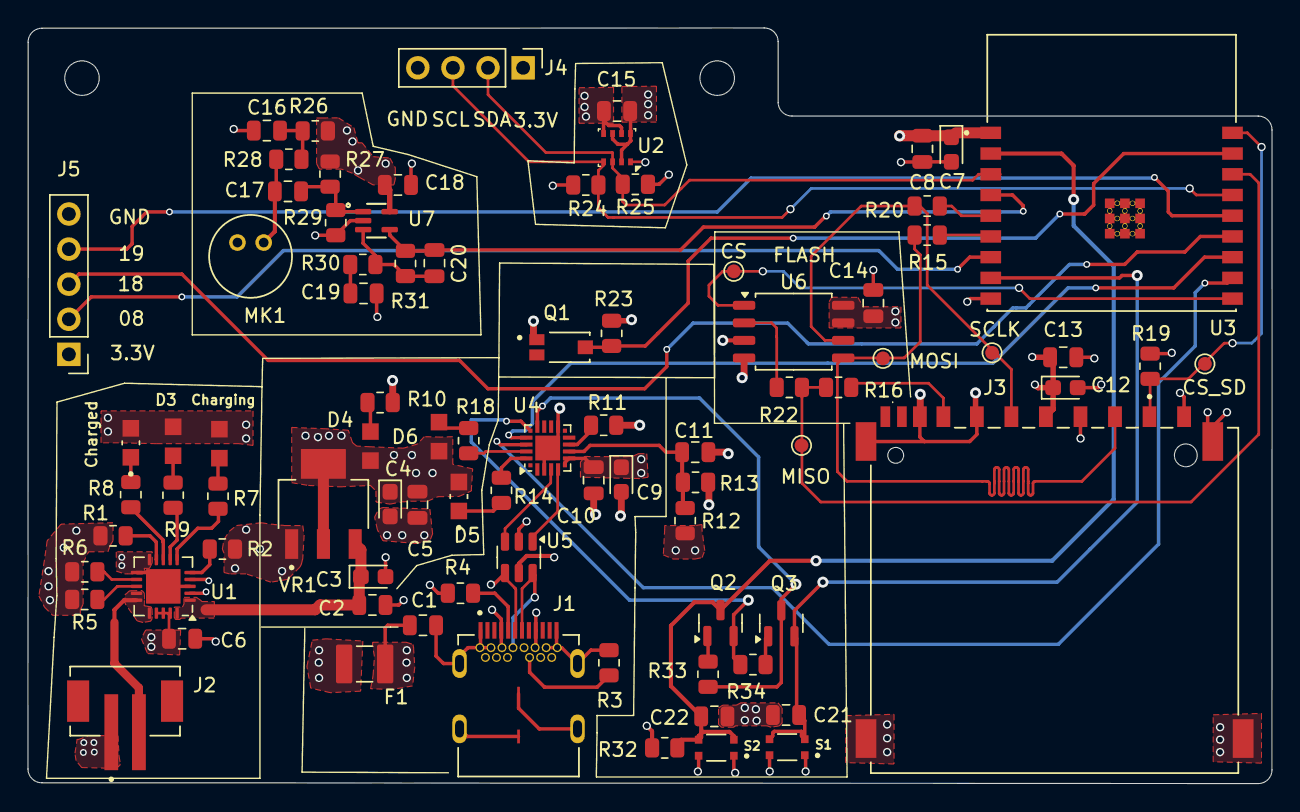
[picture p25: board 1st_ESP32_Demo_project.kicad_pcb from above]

Board: 4 copper layers, 90.0 x 54.7 mm, 85 parts (0 on the bottom side), 58 nets.

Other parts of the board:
CS: TestPoint; TestPoint_Pad_D1.0mm
CS_SD: TestPoint; TestPoint_Pad_D1.0mm
Charged: LTST-C170GKT; LED_LTST-C170GKT
Charging: LTST-C170KRKT; DIOC200X125X110
MISO: TestPoint; TestPoint_Pad_D1.0mm
MOSI: TestPoint; TestPoint_Pad_D1.0mm
SCLK: TestPoint; TestPoint_Pad_D1.0mm

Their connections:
/+5V_USB: Charged.2, Charging.+; also elsewhere on the board
/ESP32-C3-02/CS: CS.1; also elsewhere on the board
/ESP32-C3-02/CS_SD: CS_SD.1; also elsewhere on the board
/ESP32-C3-02/MISO_DO: MISO.1; also elsewhere on the board
/ESP32-C3-02/MOSI_DI: MOSI.1; also elsewhere on the board
/ESP32-C3-02/SCLK: SCLK.1; also elsewhere on the board
unnamed 35: Charging.-; also elsewhere on the board
unnamed 36: Charged.1; also elsewhere on the board
